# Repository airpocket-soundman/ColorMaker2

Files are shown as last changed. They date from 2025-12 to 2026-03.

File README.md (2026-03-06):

設定
| 設定名 | 意味 | 数値を上げると | 数値を下げると |
| --- | --- | --- | --- |
| **paint qty.** | 一回の調色で出る**絵の具の総量**  | 出る量が増える。色の比率は同じまま、**全体が濃くなる / 多く出る** | 出る量が減る。**薄くなる / 少量になる** |
| **black weight** | 黒絵の具を**どれくらい強く使うか** | **黒が強くなる**。全体が暗め・締まった色になる | **黒が弱くなる**。CMYや水寄りになり、明るめになる  |
| **gamma black** | 黒が効き始める**カーブの形** | 黒が出るのが**遅くなる**。かなり暗くなるまで黒が増えない | 黒が**早く効き始める**。少し暗くしただけでも黒が増える |
| **gamma color** | CMY（カラー）の**強さカーブ**  | 弱い色はさらに弱くなり、**強い色だけが強く出る**（メリハリが強い）  | 弱い色でも出やすくなり、**全体的に色が出やすい** |
| **threshold black** | **黒を使い始める境界** | 黒を使うのが**遅くなる**（かなり暗くならないと黒を使わない） | 黒を**早く使い始める** |
| **step delay** | ポンプの**動作スピード** | 動作が**遅くなる**（安定しやすいが時間がかかる） | 動作が**速くなる**（ただし速すぎると脱調する可能性）  |

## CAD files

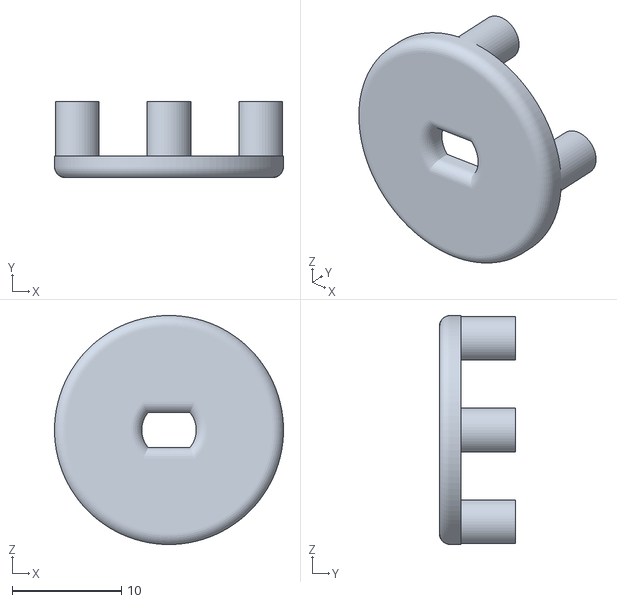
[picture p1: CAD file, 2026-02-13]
stl/pump_pulseless_core.stl
21.0 x 7.00 x 21.0

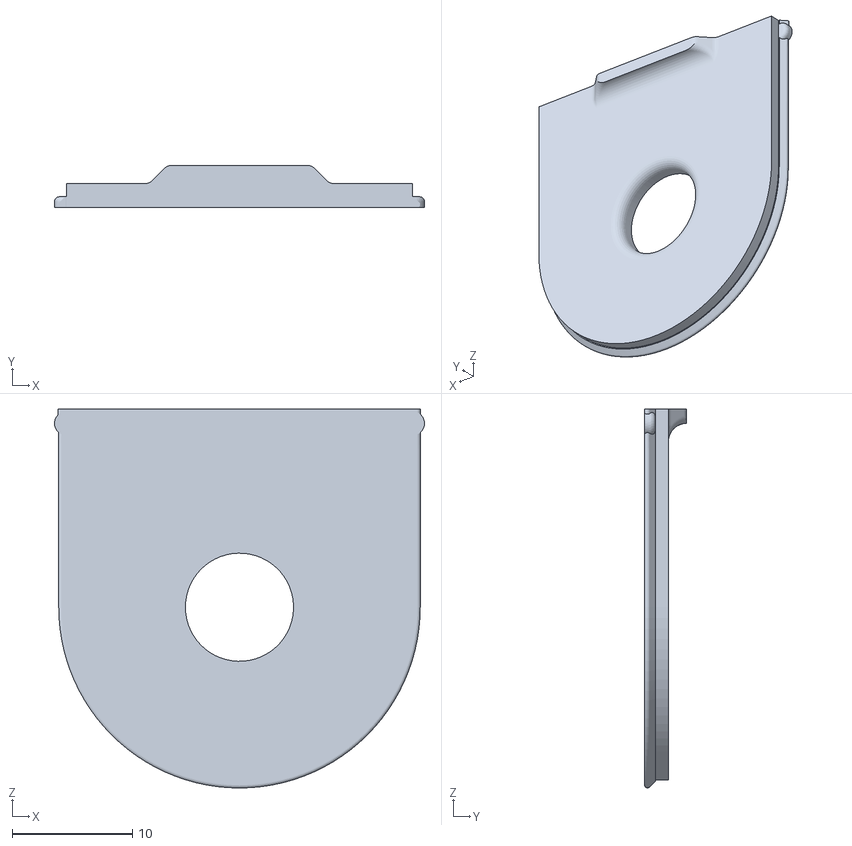
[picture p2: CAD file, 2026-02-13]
stl/roller pump cover.stl
30.8 x 3.50 x 31.5

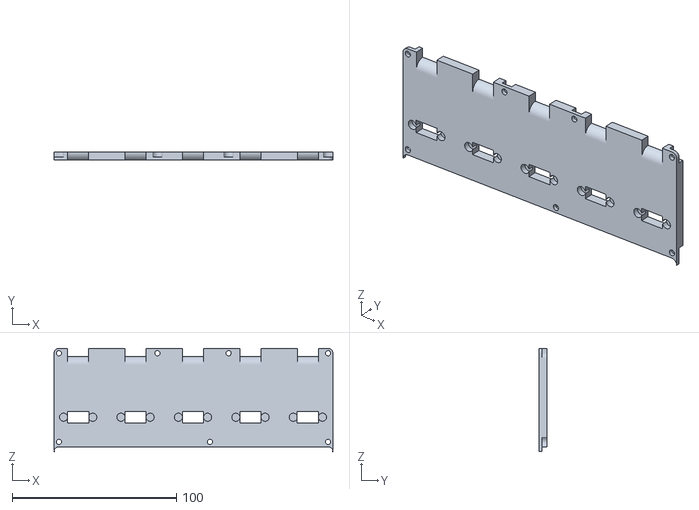
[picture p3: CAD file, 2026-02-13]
stl/pump floor.stl
170.0 x 5.00 x 63.0

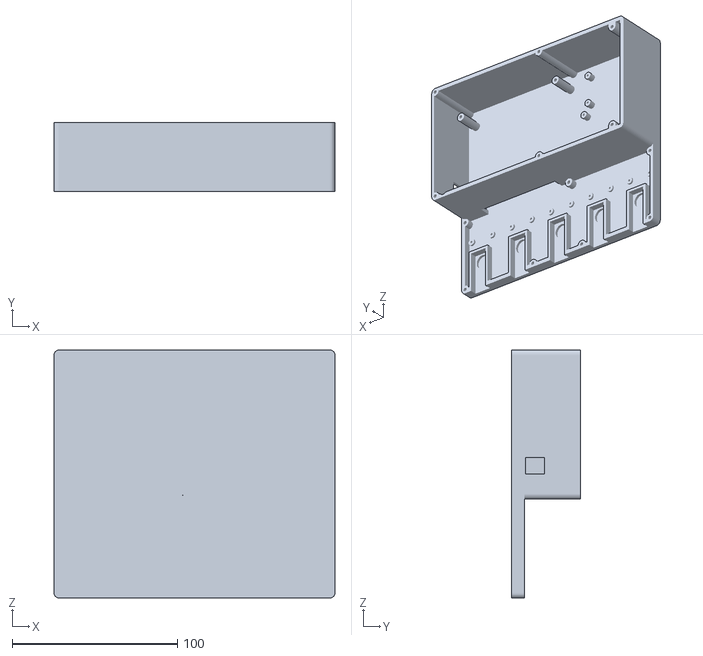
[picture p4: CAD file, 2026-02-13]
stl/box bottom.stl
170.0 x 42.0 x 150.0

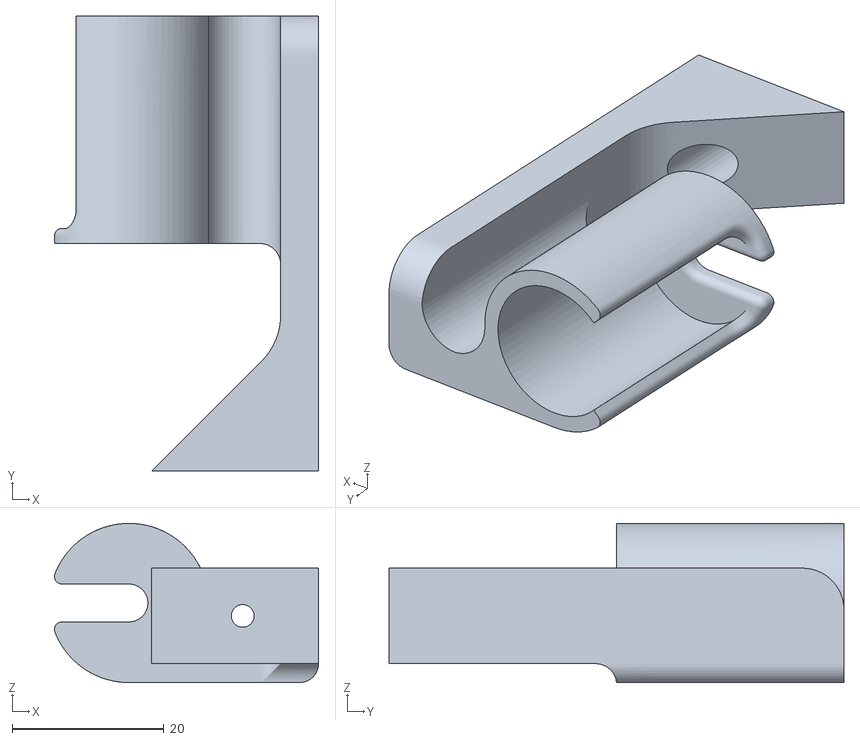
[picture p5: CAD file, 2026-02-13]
stl/tank holder.stl
34.8 x 60.0 x 21.0

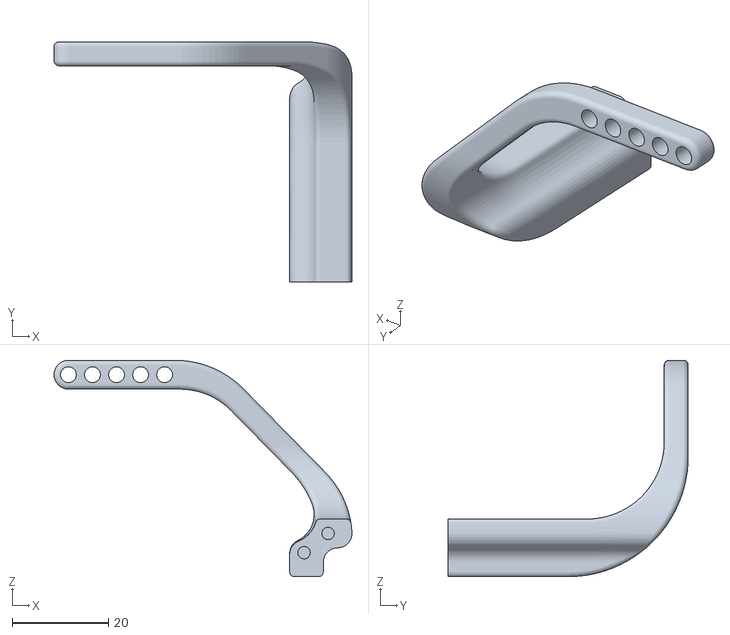
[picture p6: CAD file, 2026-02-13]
stl/tube clamp.stl
62.0 x 50.0 x 45.0

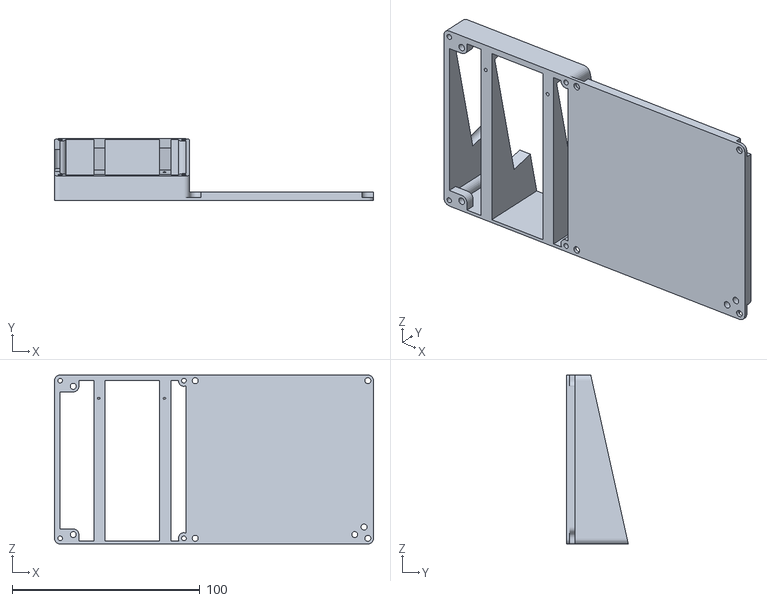
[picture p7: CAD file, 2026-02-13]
stl/box middle.stl
170.0 x 32.9 x 90.0

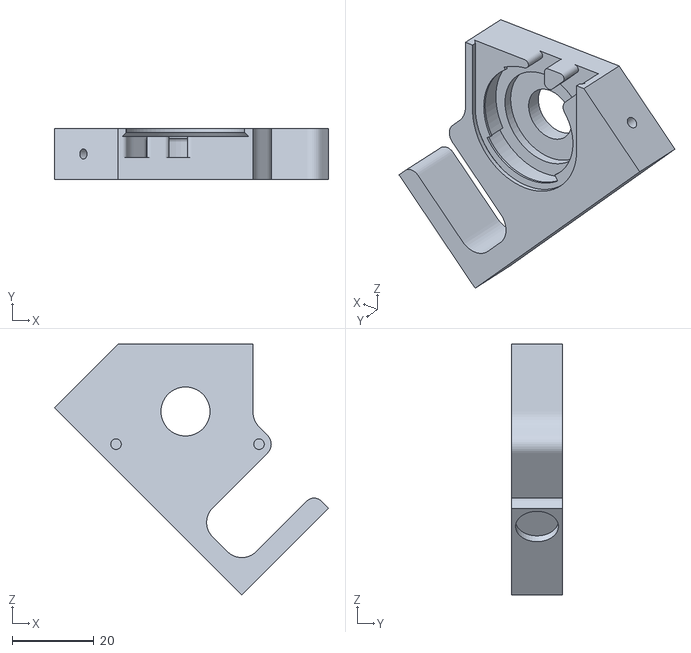
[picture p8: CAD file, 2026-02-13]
stl/pump_pulseless.stl
67.1 x 12.6 x 61.4

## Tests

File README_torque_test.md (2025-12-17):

# 28BYJ-48 + A4988（Raspberry Pi Pico）トルクテスト手順

## 1. 目的

このプロジェクトは、改造した **28BYJ-48 ステッピングモーター** を **A4988 ドライバ** で駆動し、**Raspberry Pi Pico** で制御するための **トルクおよび脱調評価用セットアップ** です。

目的:
- 負荷時の脱調限界を特定する
- 各マイクロステップモードでのトルク特性を比較する
- ステップ周波数が安定性に与える影響を評価する
- 実用アプリ向けの最適なマイクロステップと速度設定を選定する

本セットアップは **再現性・電気的安全性・挙動の明確さ** を重視し、抽象化よりも実挙動の理解を優先します。

---

## 2. ハードウェア選定の理由

### 2.1 Raspberry Pi Pico
- MicroPython でも安定した GPIO タイミング
- A4988 に適合する 3.3V ロジック
- USB シリアルでリアルタイムにパラメータ制御

### 2.2 A4988 ステッピングドライバ
- STEP / DIR インターフェイス（シンプルで決定論的）
- ハードウェア電流制限（Vref 調整可）
- マイクロステップ対応（フル～1/16）
- 電気的挙動が広く理解されている

### 2.3 28BYJ-48 ステッピングモーター（改造版）
- 元はユニポーラ（5 線式）
- **赤の共通線を切り離し、バイポーラに改造**
- 減速ギアで低速時の保持トルクが高い
- 安全性のため **5V モーター電源** で使用

> 注: このセットアップでは、28BYJ-48 のコイル電流に対して Vref が安全な値に調整済みであることを前提とします。

---

## 3. 配線

### 3.1 制御信号配線

| A4988 ピン | Pico GPIO |
|---|---|
| ENABLE | GP2 |
| DIR | GP3 |
| STEP | GP4 |
| MS1 | GP6 |
| MS2 | GP7 |
| MS3 | GP8 |
| GND | GND（共通） |

- ENABLE は **LOW アクティブ**
- MS ピンは **GPIO 直結で可（抵抗不要）**
- ロジック電圧: 3.3V（Pico）で問題なし

### 3.2 電源

- VMOT: 5V（モーター電源）
- VDD : 3.3V（ロジック電源）
- GND は Pico と A4988 で共通にすること

---

## 4. マイクロステップ設定（A4988）

| MS1 | MS2 | MS3 | モード |
|-----|-----|-----|---|
| L | L | L | フル |
| H | L | L | 1/2 |
| L | H | L | 1/4 |
| H | H | L | 1/8 |
| H | H | H | 1/16 |

マイクロステップモードは Pico の GPIO で選択し、シリアルコマンドで変更可能。
**モード変更はモーター停止中に行うこと。**

---

## 5. 制御方法

### 5.1 STEP 信号
- 明示的に STEP パルスを生成
- パルス幅は保証（>5 µs）
- パルス間の待ち時間で周波数を制御

### 5.2 速度制御
- 速度は **STEP パルス間隔（µs）** で定義
- 待ち時間が短いほど速度上昇 → トルク余裕が減る

RPM などの抽象化を避け、直感的にトルクテストできる。

---

## 6. シリアルインターフェイス

### 6.1 速度制御
改行付きの数値を送信:

```
2000
1000
500
```

→ STEP の待ち時間（µs）を設定。

### 6.2 マイクロステップ制御
以下の文字列のいずれかを送信:

```
full
half
quarter
eighth
sixteenth
```

→ マイクロステップモードを変更（安全のための待ち時間を伴う）。

---

## 7. 推奨テスト手順

1. 以下で開始:
   - `full`
   - `2000 µs`
2. 待ち時間を段階的に短く:
   - 1500 → 1000 → 800 → 600 → ...
3. 機械的負荷を与える
4. 脱調が起きた待ち時間を記録
5. 各マイクロステップモードで繰り返す

これにより **トルク vs 速度 vs マイクロステップ** の定量比較が可能。

---

## 8. 設計方針

- **最大トルク基準としてフルステップ** を使用
- マイクロステッピングは **共振抑制とスムーズさ向上の手段** と捉え、トルク増強目的ではない
- 電気的安定性のため ENABLE は常時アクティブ
- 純粋なトルク限界を測るため加速ランプは使用しない

---

## 9. 想定される結果

- 脱調境界の明確化
- 共振に敏感な速度帯の把握
- エビデンスに基づくマイクロステップ選択
- 実負荷下での安定したモーター挙動

---

## 10. 注意

- 温度上昇が見られたら Vref かデューティを下げる
- すぐ脱調する場合は速度を下げるか配線を確認
- 本セットアップは **評価用途** であり量産制御を想定しない

---

## 11. ファイル

- `main.py`: MicroPython 制御コード
- `README.md`: 本書

---

以上。

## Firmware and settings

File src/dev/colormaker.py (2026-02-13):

from machine import UART
from machine import Pin
import time
import utime


uart0 = UART(0)

enable = Pin(2,Pin.OUT)
direction = Pin(3,Pin.OUT)

stepW = Pin(9,Pin.OUT)
stepC = Pin(5,Pin.OUT)
stepM = Pin(6,Pin.OUT)
stepY = Pin(7,Pin.OUT)
stepK = Pin(8,Pin.OUT)


enable(1)

stepC(0)
stepM(0)
stepY(0)
stepK(0)
stepW(0)
   
    
class motor():
    def __init__(self):

        self.C = 0
        self.M = 0
        self.Y = 0
        self.K = 0
        self.W = 0
        self.Cx = 1
        self.Mx = 1
        self.Yx = 1
        self.Kx = 1
        self.Wx = 1
        self.stepX = 1
        self.stepNumC = 0
        self.stepNumM = 0
        self.stepNumY = 0
        self.stepNumK = 0
        self.stepNumW = 0
        self.maxStepNum = 0
        self.targetSteps = 2000
        print("motor initialized")

    def calcSteps(self):
        print("drive!!")
        self.stepNumC = self.C * self.Cx
        self.stepNumM = self.M * self.Mx
        self.stepNumY = self.Y * self.Yx
        self.stepNumK = self.K * self.Kx
        self.stepNumW = (100 - self.K) * self.Wx * self.stepX
        self.maxStepNum = max(self.stepNumC, self.stepNumM, self.stepNumY, self.stepNumK)
        stepNumAdd = self.stepNumC + self.stepNumM + self.stepNumY + self.stepNumK
        if stepNumAdd > 0:
            self.stepX = round(self.targetSteps/stepNumAdd)
            self.stepNumC = self.stepNumC * self.stepX
            self.stepNumM = self.stepNumM * self.stepX
            self.stepNumY = self.stepNumY * self.stepX
            self.stepNumK = self.stepNumK * self.stepX
            self.stepNumW = self.stepNumW * self.stepX
            stepNumAdd = self.stepNumC + self.stepNumM + self.stepNumY + self.stepNumK
            self.maxStepNum = self.maxStepNum * self.stepX
                
        print("maxStepNum = " + str(self.maxStepNum))
        print("stepNumAdd = " + str(stepNumAdd))
        print("stepX = " + str(self.stepX))
        print("stepNumC = " + str(self.stepNumC))
        print("stepNumM = " + str(self.stepNumM))
        print("stepNumY = " + str(self.stepNumY))
        print("stepNumK = " + str(self.stepNumK))
        print("stepNumW = " + str(self.stepNumW))
        
        motor.drive()
        
    def drive(self):

        direc = 0
        step_delay = 2000   # ここは自由に調整（例：2000〜4000）

        direction(direc)
        enable(0)           # ★ 回転中は常に ENABLE ON

        print("[DRIVE] start, delay_us =", step_delay)

        for i in range(self.maxStepNum):

            # ===== STEP ON =====
            if i < self.stepNumC:
                stepC(1)
            if i < self.stepNumM:
                stepM(1)
            if i < self.stepNumY:
                stepY(1)
            if i < self.stepNumK:
                stepK(1)

            time.sleep_us(5)   # STEPパルス幅（A4988は1us以上でOK）

            # ===== STEP OFF =====
            stepC(0)
            stepM(0)
            stepY(0)
            stepK(0)

            time.sleep_us(step_delay)

        enable(1)   # ★ 完全停止してから disable
        print("[DRIVE] end")


        enable(1)
        print(i)
        print("end")
        print("maxStepNum = " + str(self.maxStepNum))
#        print("stepNumAdd = " + str(stepNumAdd))
        print("stepX = " + str(self.stepX))
        print("stepNumC = " + str(self.stepNumC))
        print("stepNumM = " + str(self.stepNumM))
        print("stepNumY = " + str(self.stepNumY))
        print("stepNumK = " + str(self.stepNumK))
        print("stepNumW = " + str(self.stepNumW))
        
motor = motor()

while True:
#    go = input("any key to start")
    mes = ""
    c = 0
    c = uart0.any()
    while c > 0:
#        print("c = " + str(c))
        time.sleep_ms(50)
        l = uart0.readline()
        m = ""
        if l != None:
            print("=======================")
            print("catch comm")
            print(l)
            try:
#                m = l.decode("utf-8")
                m = str(l)
#                print(type(m))
                m = m[2:3]
#                print("l = " + m)
#                print(str(m))

            except:
                print("cant decode")
            
            if m == "s":
                print("Start")
                try:
                    motor.C = uart0.readline()
                    print(motor.C)
#                    motor.C = motor.C.decode("utf-8")
                    motor.C = int(motor.C)
                    print("C = " + str(motor.C))
                except:
                    print("cant read C")
                    break
                
                time.sleep(0.1)
                
                try:
                    motor.M = uart0.readline()
                    print(motor.M)
#                    motor.M = motor.M.decode("utf-8")
                    motor.M = int(motor.M)
                    print("M = " + str(motor.M))
                except:
                    print("cant read M")
                    break
                    
                time.sleep(0.1)
                
                try:
                    motor.Y = uart0.readline()
                    print(motor.Y)
#                    motor.Y = motor.C.decode("utf-8")
                    motor.Y = int(motor.Y)
                    print("Y = " + str(motor.Y))
                except:
                    print("cant read Y")
                    break
                    
                time.sleep(0.1)
                
                try:
                    motor.K = uart0.readline()
                    print(motor.K)
#                    motor.K = motor.K.decode("utf-8")
                    motor.K = int(motor.K)
                    print("K = " + str(motor.K))
                except:
                    print("cant read K")
                    break
                motor.calcSteps()
                
            else:
                print("not s")
        c = 0

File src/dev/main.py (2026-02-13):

from machine import UART, Pin
import time
import ujson
import math

# =====================
# 設定・定数（ご提示の値を初期値として反映）
# =====================
N             = 30.0   # 総パルス倍率 (1.0 = 1000 steps)
K_WEIGHT      = 0.5    # 黒(K)の着色力補正
GAMMA_K       = 1.5    # 閾値を超えた後のKの立ち上がりカーブ
GAMMA_COLOR   = 2.0    # カラーの立ち上がりカーブ（大きいほど薄い色の時の水が増える）
KW_THRESHOLD  = 30     # Kを使い始める境界線（小さいほど早く黒が出始める）
STEP_DELAY_US = 700    # モーターのパルス間隔

# --- ニュアンス維持のための追加設定 ---
RETAIN_CMY_RATIO = 0.4 # CMYの共通成分をどれだけ「残す」か (0.0〜1.0)
                       # 0.0=完全にK置換, 1.0=Kを使わずCMYのみでグレーを作る

DIR_NORMAL   = 1      
DIR_REVERSE  = 0      

# ピンアサイン
STEP_PINS = (16, 17, 18, 19, 20) # C, M, Y, K, W
DIR_PINS  = (21, 22, 26, 27, 28)
EN_PINS   = (2,  3,  4,  5,  6)

# =====================
# 初期化
# =====================
step_pins = [Pin(p, Pin.OUT) for p in STEP_PINS]
dir_pins  = [Pin(p, Pin.OUT) for p in DIR_PINS]
en_pins   = [Pin(p, Pin.OUT) for p in EN_PINS]

TOTAL_STEPS = int(N * 1000)
keys = ["c", "m", "y", "k", "w"]
mode = "manual"
pumps = {k: False for k in keys}
pumps["reverse"] = False
auto_target_steps = [0, 0, 0, 0, 0]
interrupted = False
uart = UART(0, baudrate=115200)
rx_buf = b""

# =====================
# 調色ロジック (CMY共存 + ガンマ補正版)
# =====================

def convert_to_watercolor_steps(c, m, y, k):
    # 1. グレー成分の抽出
    gray_component = min(c, m, y)
    
    # 2. CMYをどれだけ残すかの計算 (UCR調整)
    # 共通成分のうち、一部をKに置き換え、一部をCMYとして残す
    replace_to_k = gray_component * (1.0 - RETAIN_CMY_RATIO)
    
    # 置き換えられなかった分がCMYとして残り、3色混合の深みを作る
    c_raw = c - replace_to_k
    m_raw = m - replace_to_k
    y_raw = y - replace_to_k
    k_combined = k + replace_to_k

    # 3. カラー成分(C,M,Y)へのガンマ補正
    # 薄い色の時に水の比率を稼ぐ
    c_f = math.pow(c_raw / 100.0, GAMMA_COLOR) * 100
    m_f = math.pow(m_raw / 100.0, GAMMA_COLOR) * 100
    y_f = math.pow(y_raw / 100.0, GAMMA_COLOR) * 100

    # 4. K(黒)とW(水)の比率計算
    k_out = 0
    w_out = 0

    if k_combined <= KW_THRESHOLD:
        k_out = 0
        w_out = 100 
    else:
        range_width = 100 - KW_THRESHOLD
        k_input_norm = (k_combined - KW_THRESHOLD) / range_width
        k_ratio = math.pow(k_input_norm, GAMMA_K)
        
        k_out = k_ratio * 100 * K_WEIGHT
        w_out = (1.0 - k_ratio) * 100

    # 5. 比率の合成と正規化
    raw_ratios = [c_f, m_f, y_f, k_out, w_out]
    total_raw = sum(raw_ratios)
    
    if total_raw == 0:
        return [0, 0, 0, 0, 0]

    return [int((val / total_raw) * TOTAL_STEPS) for val in raw_ratios]

# =====================
# 制御・通信
# =====================

def handle_json(msg):
    global mode, pumps, auto_target_steps, interrupted
    
    print("Received JSON:", ujson.dumps(msg))
    
    cmd = msg.get("cmd", "")
    if cmd == "pump":
        mode = "manual"
        pumps.update(msg.get("pumps", {}))
        d = DIR_REVERSE if pumps.get("reverse") else DIR_NORMAL
        for pin in dir_pins: pin(d)
        for i, k in enumerate(keys): en_pins[i](0 if pumps.get(k) else 1)
        interrupted = True
        
    elif cmd == "color":
        mode = "auto"
        raw = msg.get("cmyk", {"c":0,"m":0,"y":0,"k":0})
        auto_target_steps = convert_to_watercolor_steps(raw['c'], raw['m'], raw['y'], raw['k'])
        interrupted = True

def check_uart():
    global rx_buf
    if uart.any():
        try:
            raw = uart.read()
            if raw:
                rx_buf += raw
                if b"\n" in rx_buf:
                    line, rx_buf = rx_buf.split(b"\n", 1)
                    decoded_str = line.decode().strip()
                    if decoded_str:
                        handle_json(ujson.loads(decoded_str))
                        return True
        except Exception as e:
            print("UART Error:", e)
    return False

def drive_auto_steps(step_list):
    global interrupted
    interrupted = False
    
    for i in range(5):
        if step_list[i] > 0:
            en_pins[i](0)
            dir_pins[i](DIR_NORMAL)
    
    max_s = max(step_list)
    for s in range(max_s):
        if s % 10 == 0 and check_uart():
            break 
        
        for i in range(5):
            if s < step_list[i]: step_pins[i](1)
        time.sleep_us(STEP_DELAY_US)
        for i in range(5): step_pins[i](0)
        time.sleep_us(STEP_DELAY_US)
    
    for p in en_pins: p(1)

# =====================
# メインループ
# =====================
for p in en_pins: p(1)
print("--- Watercolor Driver (Nuance-Keep Mode) ---")
print("Settings: N={}, G_COLOR={}, G_K={}, THR={}, RETAIN_CMY={}".format(N, GAMMA_COLOR, GAMMA_K, KW_THRESHOLD, RETAIN_CMY_RATIO))

while True:
    check_uart()
    
    if mode == "manual":
        any_on = False
        for i, k in enumerate(keys):
            if pumps.get(k):
                step_pins[i](1)
                any_on = True
        if any_on:
            time.sleep_us(STEP_DELAY_US)
            for p in step_pins: p(0)
            time.sleep_us(STEP_DELAY_US)
            
    elif mode == "auto":
        if sum(auto_target_steps) > 0:
            print("Auto Mixing Steps (C,M,Y,K,W):", auto_target_steps)
            drive_auto_steps(auto_target_steps)
            auto_target_steps = [0, 0, 0, 0, 0]
            if mode == "auto":
                mode = "manual"

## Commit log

2025-12-17 テストコード作成
2026-02-13 STL追加、ソース整理
    [box bottom.stl, box middle.stl, pump floor.stl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]
